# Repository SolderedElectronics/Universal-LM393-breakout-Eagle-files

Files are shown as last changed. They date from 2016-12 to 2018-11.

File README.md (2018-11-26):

# Universal LM393 breakout Eagle Files
## Image
Universal LM393 breakout image
[LDR LM393 breakout(100027)](https://e-radionica.com/en/light-sensor-with-lm393-e-radionica-made.html)
[Vibration sensor LM393 breakout(100031)](https://e-radionica.com/en/vibration-sensor-with-lm393-e-radionica-made.html)
[Raindrop LM393 breakout(100030)](https://e-radionica.com/en/humidity-sensor-with-lm393-e-radionica-made.html)
[Fire sensor LM393 breakout(100028)](https://e-radionica.com/en/fire-sensor-phototransistor-s-lm393-e-radionica-made.html)
[Hall effect LM393 breakout(100029)](https://e-radionica.com/en/hall-effect-sensor-s-lm393-e-radionica-made.html)

## Description and details
Universal LM393 is breakout for different sensors which are connected to the LM393 voltage comapator. According to the setting of the potenciometer and the value of connected sensor, you will get digital HIGH(Vcc) or LOW(0V) at digital output. Analog output is also available. Check schematics for details.

We have made versions of this board with: 
- LDR(light depending resistor)
- vibration sensor
- Hall effect sensor(pads are at the bottom side of PCB)
- Raindrop sensor
- Phototransistor(responses to IR light, can be used to detect fire or sunlight)

## Repository content
This repo contains Cadsoft Eagle .sch and .brd files for Universal LM393 board. It also contains schematic in .pdf created from .sch Eagle file. 
Files have been arranged into folders for navigating between different versions of board. 
Tip: layer 200 shows top silkscreen and layer 208 should be bottom silkscreen. tParts and bParts layers are not used in actual PCB. 

## Docs
- [Universal LM393 breakout sample product] (https://e-radionica.com/en/light-sensor-with-lm393-e-radionica-made.html)

## Board versions
- v1.0 REV A - inital published version 

## License info
This product is open-source. Yay!
For any tech questions, contact us at techsupport@e-radionica.com
If you find an Issue, please open one at GitHub. If you can improve our product, fork us.

e-radionica.com Team.

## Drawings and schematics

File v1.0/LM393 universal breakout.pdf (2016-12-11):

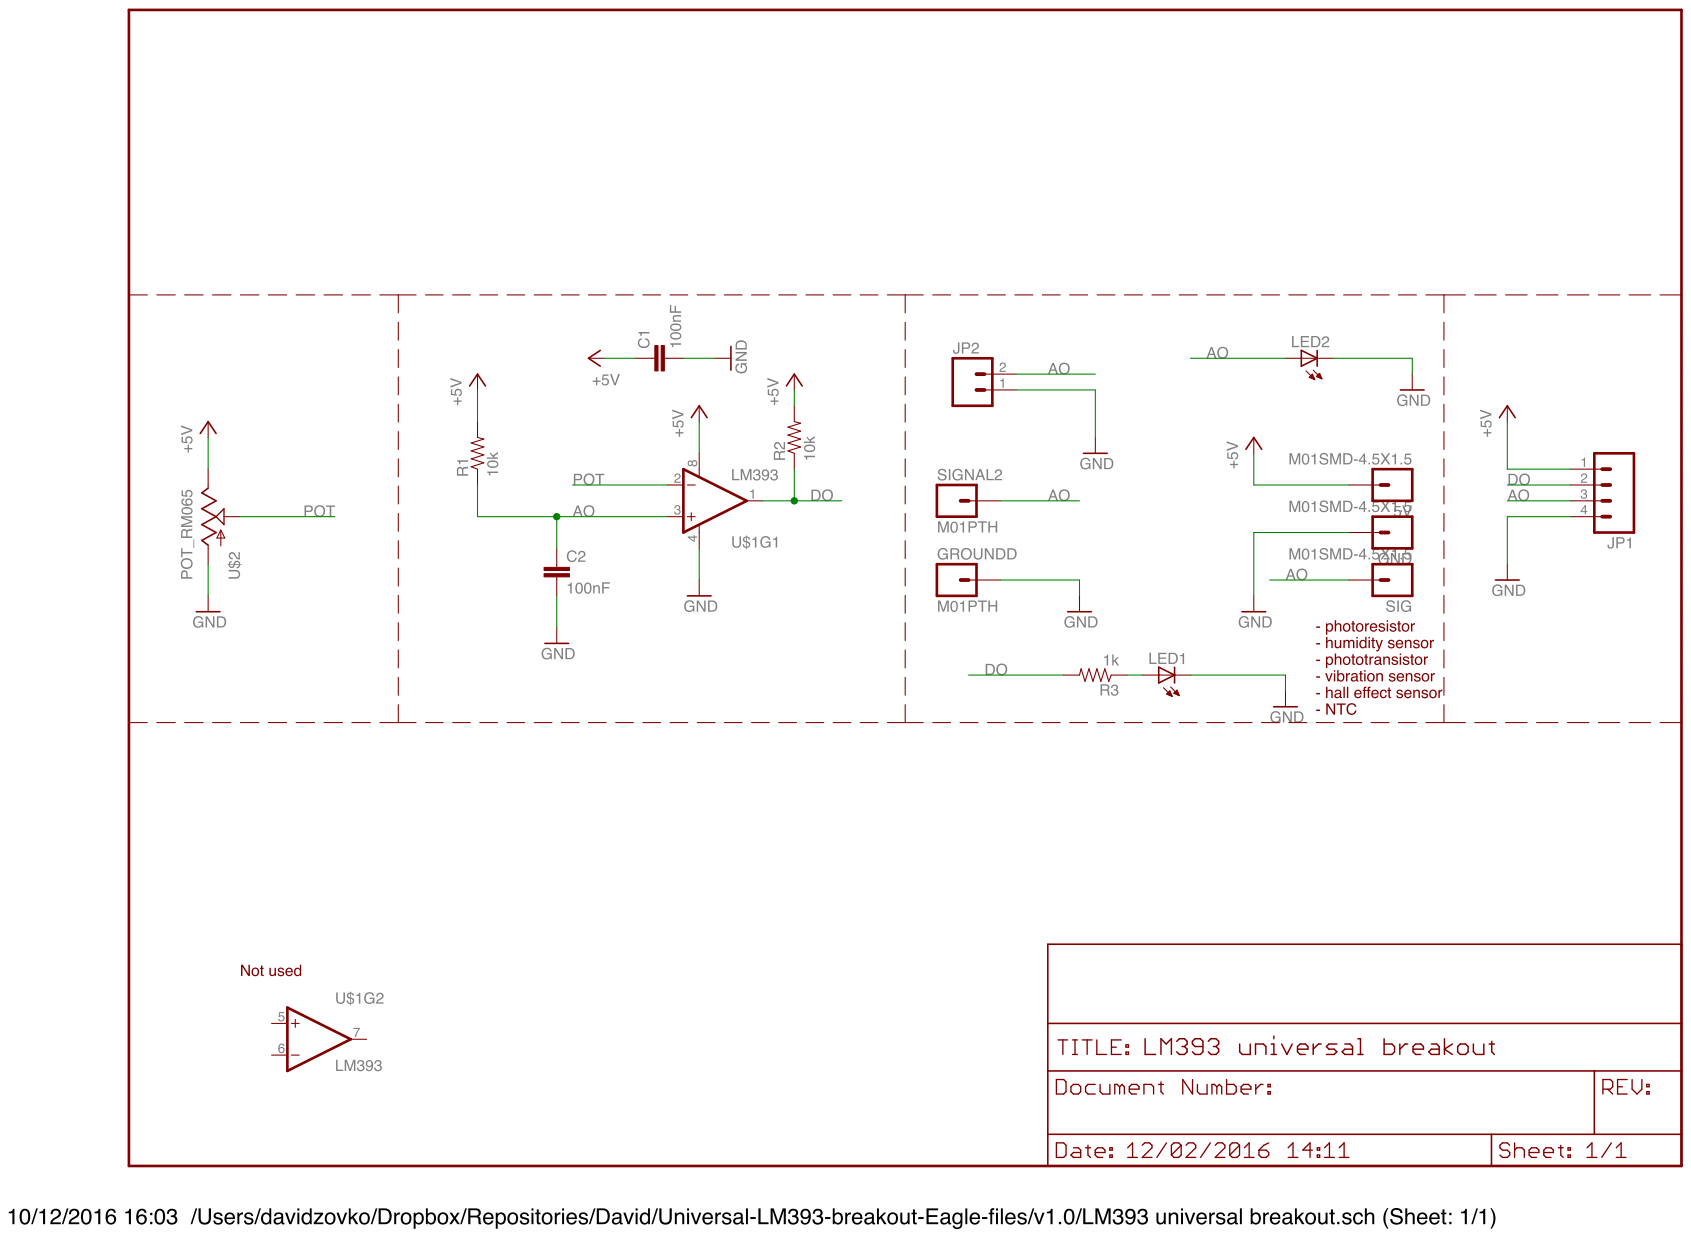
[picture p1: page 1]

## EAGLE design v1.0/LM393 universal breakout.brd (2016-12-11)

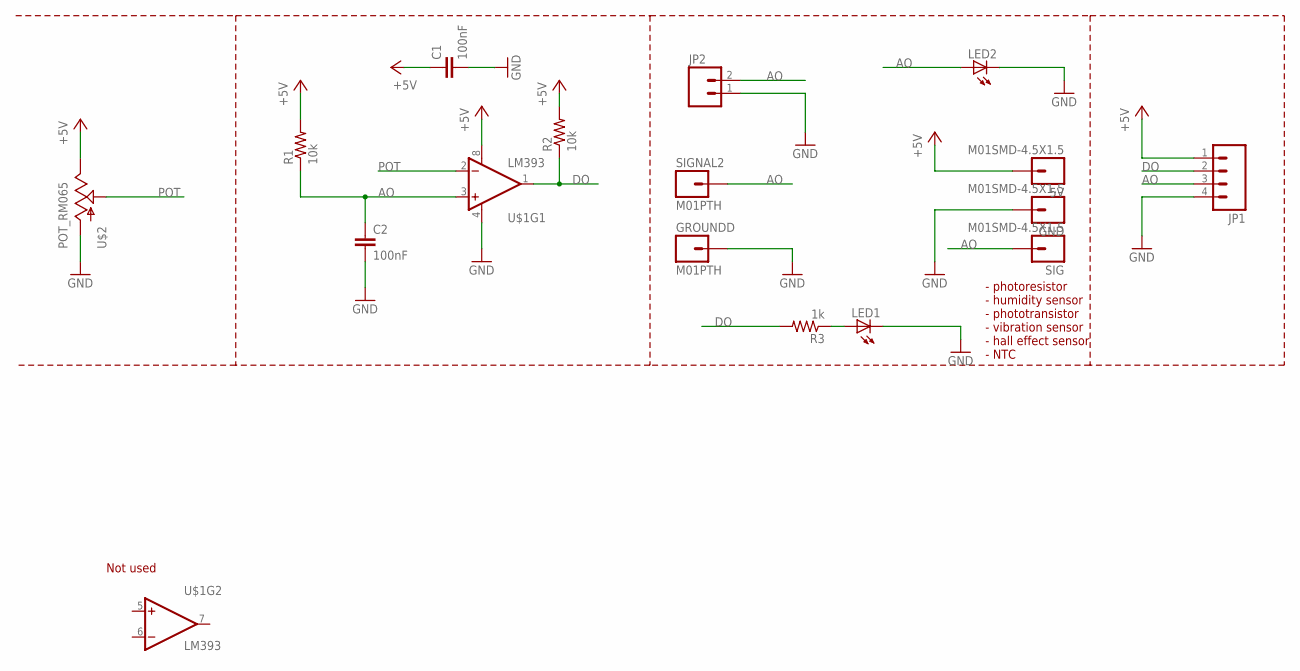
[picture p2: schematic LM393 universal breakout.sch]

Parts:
5V: M01SMD-4.5X1.5; PAD-1.5X4.5
C1, C2: 100nF; 0603-CAP
GND: M01SMD-4.5X1.5; PAD-1.5X4.5
GROUNDD: M01PTH; 1X01
JP1: M04PTH; 1X04
JP2: M02PTH; 1X02
LED1: LEDCHIP-LED0805; CHIP-LED0805
LED2: LED5MM
R1, R2: 10k; 0603-RES
R3: 1k; 0603-RES
SIG: M01SMD-4.5X1.5; PAD-1.5X4.5
SIGNAL2: M01PTH; 1X01
U$1: LM393; SO08
U$2: POT_RM065; RM065

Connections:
+5V: 5V.P$1, C1.1, JP1.1, R1.2, R2.2, U$1.8 (V+), U$2.3 (E)
AO: C2.1, JP1.3, JP2.2, LED2.A, R1.1, SIG.P$1, SIGNAL2.1, U$1.3 (+IN)
DO: JP1.2, R2.1, R3.2, U$1.1 (OUT)
GND: C1.2, C2.2, GND.P$1, GROUNDD.1, JP1.4, JP2.1, LED1.C, LED2.K (C), U$1.4 (V-), U$2.1 (A)
unnamed: LED1.A, R3.1
POT: U$1.2 (-IN), U$2.2 (S)

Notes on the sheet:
Not used
- photoresistor - humidity sensor - phototransistor - vibration sensor - hall effect sensor - NTC

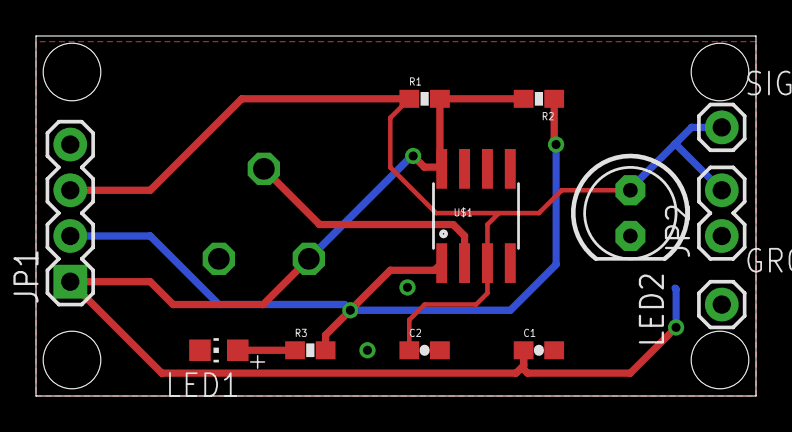
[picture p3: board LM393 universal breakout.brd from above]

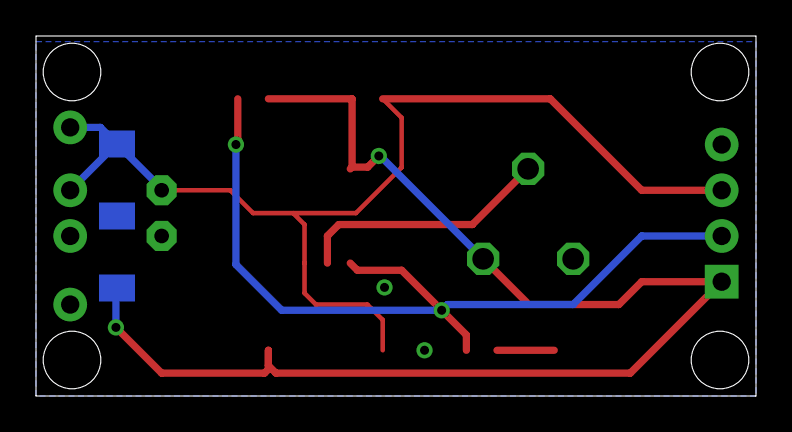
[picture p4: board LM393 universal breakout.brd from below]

Board: 2 copper layers, 40.0 x 20.0 mm, 20 parts (3 on the bottom side), 6 nets.

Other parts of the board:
U$3: NOVI_LOGO-4MM
U$4: OSH3MM
U$5: LUDI_LOGO_BACK
U$6: E-RADIONICA.COM_MADE_IN_BACK!

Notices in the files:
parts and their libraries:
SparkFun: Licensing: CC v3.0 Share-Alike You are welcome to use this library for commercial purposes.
